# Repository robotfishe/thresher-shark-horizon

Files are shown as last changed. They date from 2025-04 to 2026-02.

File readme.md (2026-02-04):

### Meet the Thresher Shark Horizon, a split keyboard (plus optional numpad) for Gateron low profile keyswitches, with a couple of unique features.

Note: this repo isn't complete yet, but there should be enough to build your own TSH if you want.

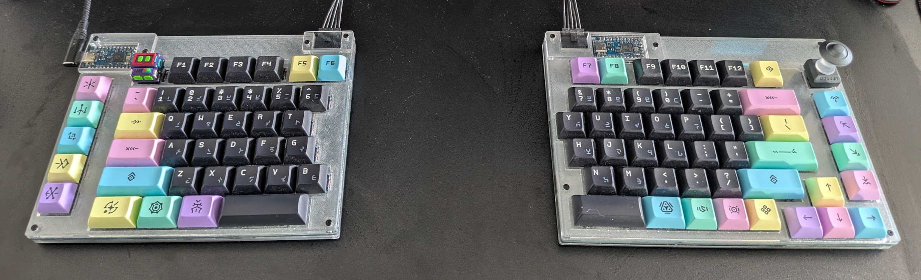
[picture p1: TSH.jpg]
photo of a split keyboard


The name comes from one of my favourite animals, the thresher shark, a creature endowed with a permanent facial expression that can only be described as "why is existence happening to me":

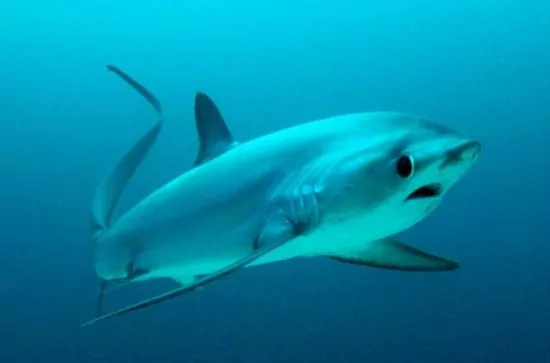
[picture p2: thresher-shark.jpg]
image of a thresher shark


and my favourite video game series, Horizon Zero Dawn/Horizon Forbidden West. Since the general approach to naming a keyboard design seems to be "throw a dart at a dictionary", this seemed as good as anything.

The TSH keyboard has a couple of design choices that set it apart:
- It uses Gateron low profile switches, which are a lot less commonly supported in the custom keyboard space than other switch types.
- It mostly uses a full standard ANSI key layout, somewhat rare among split keyboards.
- It has an electrically coupled split spacebar (see below for what that means).
- It uses a Molex Micro-fit cable to connect the split halves rather than a TRRS (see below for why).

The TSH numberpad, meanwhile: 
- Is a separate, optional unit that needs its own USB connection.
- Has a built-in OLED screen and can function as a standalone 4-function calculator.

All three parts are "sandwich" designs using layers of laser-cut acrylic. The only part that needs a different fabrication approach is the switch plate - see details in the building section below.

### Electrically coupled split spacebar: what and why?
The TSH uses what I call an "electrically coupled split spacebar" design. What that means is that the two halves of the spacebar are connected directly to each other via two extra conductors in the cable between the two keyboard halves. Because of this, the keyboard firmware actually *sees them as a single key*.

I designed the keyboard this way because I have a habit of slamming both my thumbs down on the spacebar at once, and I didn't want to risk that with a split layout that might lead to lots of accidental double-spaces. I could have fixed that in software somehow, but this was a cleaner solution. If you're not a double-space-slammer, you won't notice any difference at all, *except* for the fact that the right spacebar "doesn't exist" in software, so it can't be reassigned to another function.

### Molex Micro-fit connectors: what and why?
The two halves of the TSH are connected with a Molex Micro-fit 3.0 5-pin cable. There are two main advantages of this connector over the TRRS jacks that are traditionally used in split keyboards:

First, the connectors are parallel, so the cable is hot-plug-safe (TRRS cables, because the various contacts pass through in sequence when you connect them, are usually NOT hot-pluggable because you will end up inadvertently dumping voltage somewhere you don't want it).

Second, Micro-fit connectors are crimped rather than soldered, so putting together your own cable with custom sleeving should be easier. Pre-built cable assemblies are also readily available.

### Compatible parts and bill of materials
The TSH is designed for Gateron low profile switches. You can also use Nuphy-branded low profile switches, which are made by Gateron to the same dimensions. You'll need:
- 41 switches for the left half
- 49 for the right half
- 19 for the numpad (optional)

You'll need a microcontroller board for each half, and a third for the numberpad if you decide to build that as well. It's designed for the [Elite-Pi](https://keeb.io/products/elite-pi-usb-c-pro-micro-replacement-rp2040), but there's no reason I know of the slightly older Elite-C wouldn't work.

Other parts you'll need:
- 9 stabilisers (all 2U size), available on [Gateron's website](https://www.gateron.com/products/gateron-low-profile-plate-mounted-stabilizer).
- 220 hot-swap sockets (+50 more for the numpad, optional) - the board is desigend for [Mill-Max 3305s](https://www.digikey.co.uk/en/products/detail/mill-max-manufacturing-corp/3305-0-15-80-47-27-10-0/13901970) under both the keyswitches and MCUs
- 2 [Molex Micro-Fit 3.0 5-pin receptacles](https://www.molex.com/en-us/products/part-detail/436500500)
- 1 [Molex Micro-Fit 3.0 5-pin cable assembly](https://www.molex.com/en-us/products/part-detail/2147501052)
- 90 1N4148 signal diodes (+ 19 more for the numpad, optional)

Finally, you'll need an assortment of M2 screws and M2x3 barrel nuts. For my build, I used 6mm long barrel nuts from [this Aliexpress listing](https://www.aliexpress.com/item/1005007555263192.html?spm=a2g0o.order_list.order_list_main.26.3d2e1802AlYUGI) with 8mm M2 screws for the thinner parts of the boards and 12mm ones for the thicker parts (around the controllers). There's some flexibility in these lengths and you might find that you need something slightly different given the variation in how thick a "2mm" piece of acrylic actually is, among other things.

### Fabrication and building

This section is coming soon :)

### Software
The TSH is designed for use with [KMK](https://github.com/KMKfw/kmk_firmware), a keyboard firmware built on top of CircuitPython. I think QMK would also work, but I could never get it to install on any of my RP2040 boards, so this hasn't been tested.

If you want the calculator function on the numpad, use [my fork of KMK](https://github.com/robotfishe/kmk_firmware). Be warned that I do not keep this up to date with the upstream build....but it's a keyboard, so if it works, it works, right?

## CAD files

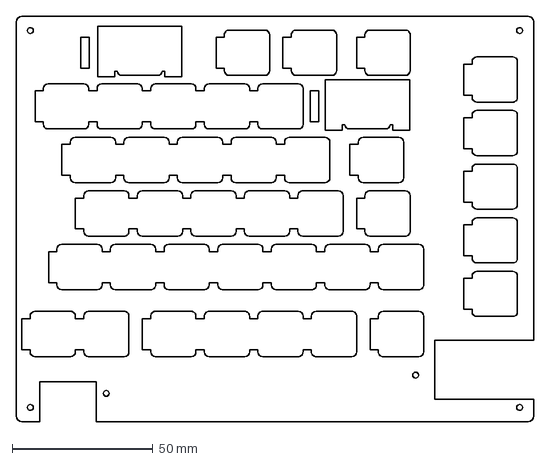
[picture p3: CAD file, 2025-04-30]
left-half/lasercut-files/left-plate-support.dxf
184.0 x 144.0 mm

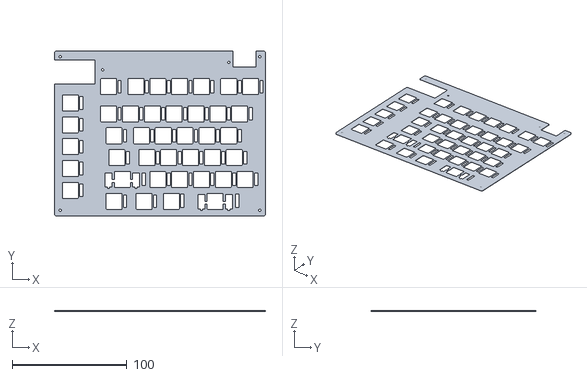
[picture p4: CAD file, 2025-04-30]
left-half/plate-files/left-plate.stl
184.0 x 144.0 x 1.00

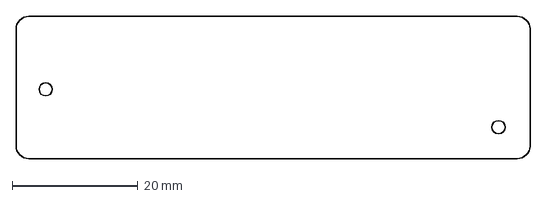
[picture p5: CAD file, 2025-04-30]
right-half/lasercut-files/right-mcu-cover.dxf
81.7 x 22.6 mm

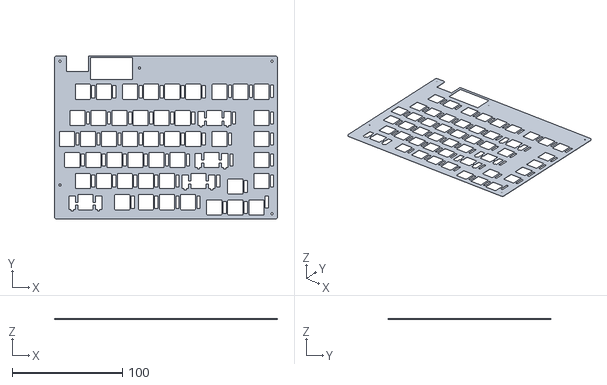
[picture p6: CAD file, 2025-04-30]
right-half/plate-files/right-plate.stl
202.0 x 148.0 x 1.00

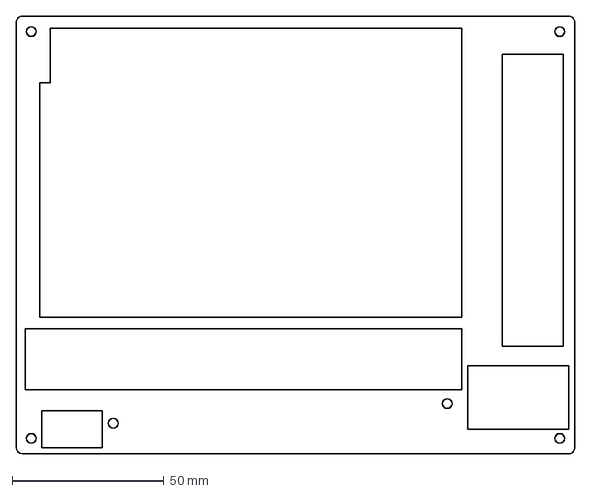
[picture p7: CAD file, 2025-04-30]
left-half/lasercut-files/left-foam-frame.dxf
184.0 x 144.0 mm

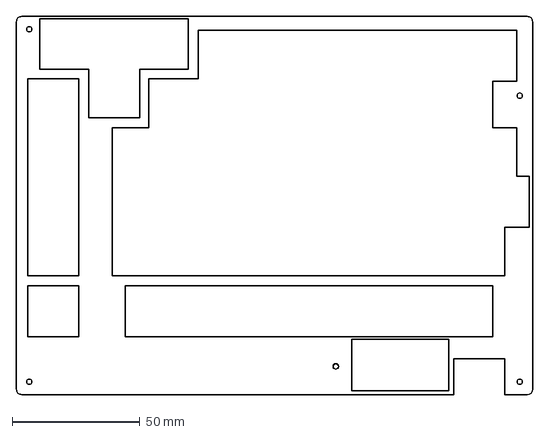
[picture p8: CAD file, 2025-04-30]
right-half/lasercut-files/right-lid.dxf
202.0 x 148.0 mm

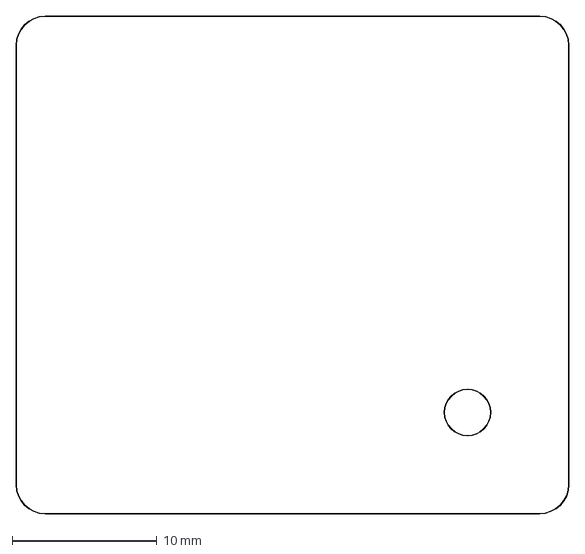
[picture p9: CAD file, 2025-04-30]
left-half/lasercut-files/left-mcu-cover.dxf
38.2 x 34.4 mm

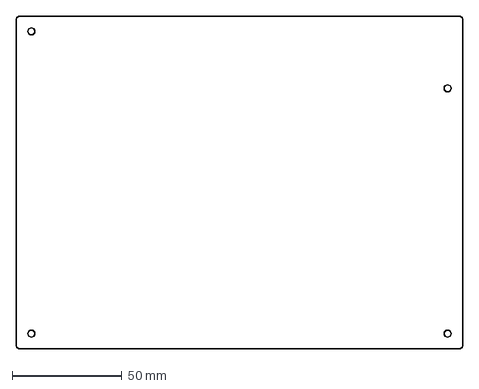
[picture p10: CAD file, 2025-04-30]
right-half/lasercut-files/right-base.dxf
204.0 x 152.0 mm

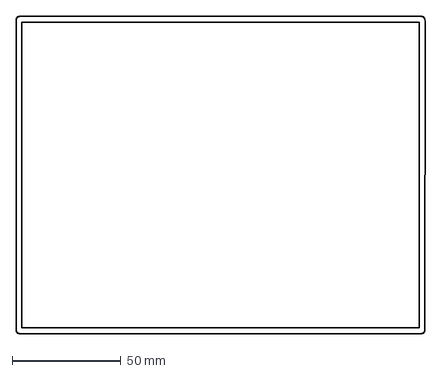
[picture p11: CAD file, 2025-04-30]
left-half/lasercut-files/left-frame.dxf
188.0 x 146.0 mm

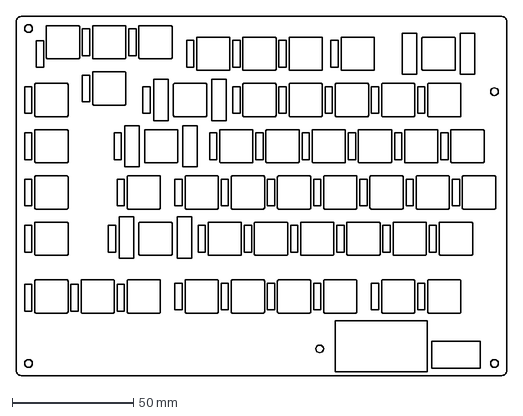
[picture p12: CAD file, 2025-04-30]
right-half/lasercut-files/right-pcb-support.dxf
202.0 x 148.0 mm

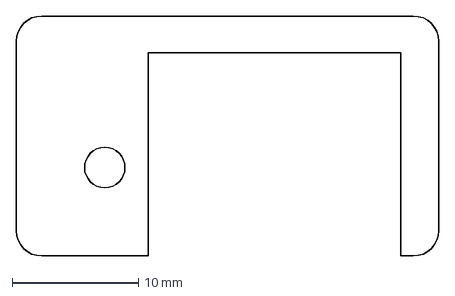
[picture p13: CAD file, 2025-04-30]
left-half/lasercut-files/left-connector-spacer.dxf
33.4 x 19.0 mm

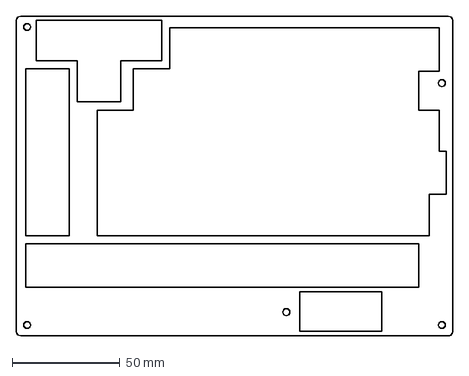
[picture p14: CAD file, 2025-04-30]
right-half/lasercut-files/right-foam-frame.dxf
202.0 x 148.0 mm

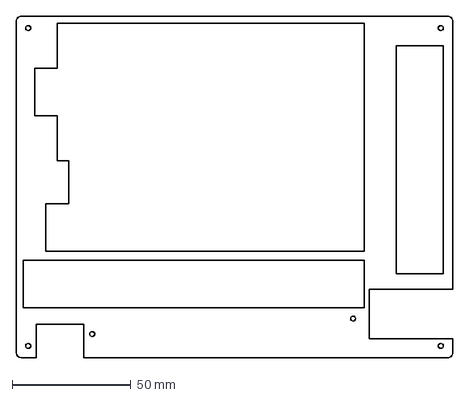
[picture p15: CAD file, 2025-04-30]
left-half/lasercut-files/left-lid.dxf
184.0 x 144.0 mm

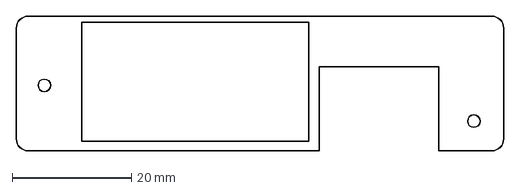
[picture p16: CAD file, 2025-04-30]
right-half/lasercut-files/right-mcu-spacer.dxf
81.7 x 22.6 mm

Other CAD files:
left-half/lasercut-files/left-base.dxf
right-half/lasercut-files/right-plate-support.dxf
left-half/lasercut-files/left-connector-cover.dxf
left-half/lasercut-files/left-pcb-support.dxf
left-half/lasercut-files/left-mcu-spacer.dxf
left-half/plate-files/left-plate.dxf
right-half/plate-files/right-plate.dxf
